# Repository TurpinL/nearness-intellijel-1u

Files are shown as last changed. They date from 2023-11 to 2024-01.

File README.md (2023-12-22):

# Nearness-Intellijel 1U

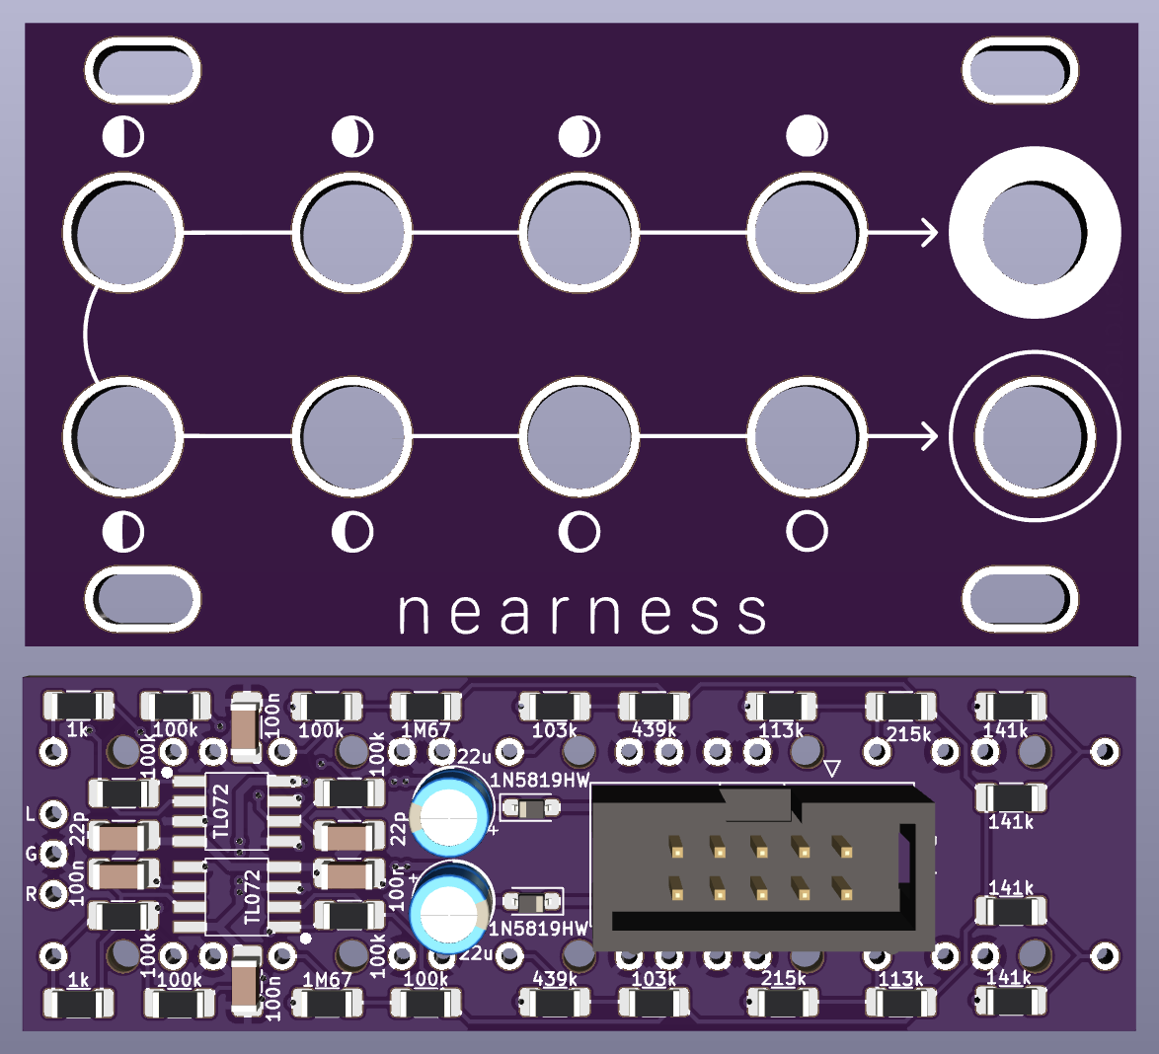
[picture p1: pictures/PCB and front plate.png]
Nearness Intellijel 1u


This is an adaption of [sonocircuit's nearness module 1u adaptation](https://github.com/sonocircuit/Nearness-1U) (Which itself is an 1u adaptation of [sarnesjo's nearness module](https://github.com/sarnesjo/nearness)) now in 1U Intellijel format. 

### Changes made:

- The back PCB is now 22.5mm high to fit Intellijel's spec
- Rearranged jacks, new faceplate
- 14hp
- Slightly adjusted resistor values based on availiability 

## Making your own

[Digikey BOM](https://www.digikey.com.au/en/mylists/list/PDI5ANLO88) **Note**: 3 pin header, 2x5 pin IDC Box header and jacks not included.

**WARNING**: I haven't yet assembled one of these to test it, there may be errors in and or all components of this. Build at your own risk!

**WARNING**: Watch out for the 3 pin header. It has to be soldered before the jacks, otherwise it's pads are inaccessible. You'll also want to trim its leads so they don't stick too far out the back of the PCB. It's best if the resulting solder mound is flat or recessed, otherwise it risks shorting out in the jack and/or the jack not sitting flat.

## Licence

Thanks to sarnesjo and sonocircuit for sharing! Same licence applies.

[CC BY-SA 4.0](http://creativecommons.org/licenses/by-sa/4.0/)

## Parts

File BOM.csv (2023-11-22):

# | Reference | Qty | Value | Footprint | Source
1 | C1, C2 | 2 | 22p | Capacitor_SMD:C_1206_3216Metric_Pad1.33x1.80mm_HandSolder | https://www.digikey.com.au/en/products/detail/w%C3%BCrth-elektronik/885012008039/5453738
2 | C3, C4 | 2 | 22u | Capacitor_THT:CP_Radial_D5.0mm_P2.00mm | https://www.digikey.com.au/en/products/detail/panasonic-electronic-components/ECE-A1EKA220/6921
3 | C5, C6, C7, C8 | 4 | 100n | Capacitor_SMD:C_1206_3216Metric_Pad1.33x1.80mm_HandSolder | https://www.digikey.com.au/en/products/detail/kemet/C1206C104K5RAC7210/3317012
4 | D1, D2 | 2 | Schottky | Diode_SMD:D_SOD-323_HandSoldering | https://www.digikey.com.au/en/products/detail/toshiba-semiconductor-and-storage/CUS10S40-H3F/5114300
5 | J1, J2, J3, J4, J5, J6, J7, J8, J9, J10 | 10 | PJ398SM | nearness: PJ398SM | https://www.thonk.co.uk/shop/thonkiconn/
6 | P1 | 1 | CONN_01X03 | nearness:Pin_1x3
7 | P7 | 1 | CONN_01X03 | Connector_IDC:IDC-Header_2x05_P2.54mm_Vertical
8 | R1, R14, R15, R17, R19, R20, R21, R22 | 8 | 100k | Resistor_SMD:R_1206_3216Metric_Pad1.30x1.75mm_HandSolder | https://www.digikey.com.au/en/products/detail/stackpole-electronics-inc/RMCF1206FT100K/1759689
9 | R2, R13 | 2 | 1M65 | Resistor_SMD:R_1206_3216Metric_Pad1.30x1.75mm_HandSolder | https://www.digikey.com.au/en/products/detail/vishay-dale/CRCW12061M65FKEA/1177009
10 | R3, R12 | 2 | 102k | Resistor_SMD:R_1206_3216Metric_Pad1.30x1.75mm_HandSolder | https://www.digikey.com.au/en/products/detail/stackpole-electronics-inc/RMCF1206FT102K/1759691
11 | R4, R11 | 2 | 442k | Resistor_SMD:R_1206_3216Metric_Pad1.30x1.75mm_HandSolder | https://www.digikey.com.au/en/products/detail/yageo/RC1206FR-07442KL/728921
12 | R5, R10 | 2 | 113k | Resistor_SMD:R_1206_3216Metric_Pad1.30x1.75mm_HandSolder | https://www.digikey.com.au/en/products/detail/vishay-dale/CRCW1206113KFKEA/1176877
13 | R6, R9 | 2 | 215k | Resistor_SMD:R_1206_3216Metric_Pad1.30x1.75mm_HandSolder | https://www.digikey.com.au/en/products/detail/yageo/RC1206FR-07215KL/728686
14 | R7, R8, R25, R26 | 4 | 140k | Resistor_SMD:R_1206_3216Metric_Pad1.30x1.75mm_HandSolder | https://www.digikey.com.au/en/products/detail/yageo/RC1206FR-07140KL/728550
15 | R23, R24 | 2 | 1k | Resistor_SMD:R_1206_3216Metric_Pad1.30x1.75mm_HandSolder | https://www.digikey.com.au/en/products/detail/stackpole-electronics-inc/RMCF1206FT1K00/1759616
16 | U1, U2 | 2 | TL072 | nearness:SOIC-8 | https://www.digikey.com.au/en/products/detail/texas-instruments/TL072HIDR/15205173

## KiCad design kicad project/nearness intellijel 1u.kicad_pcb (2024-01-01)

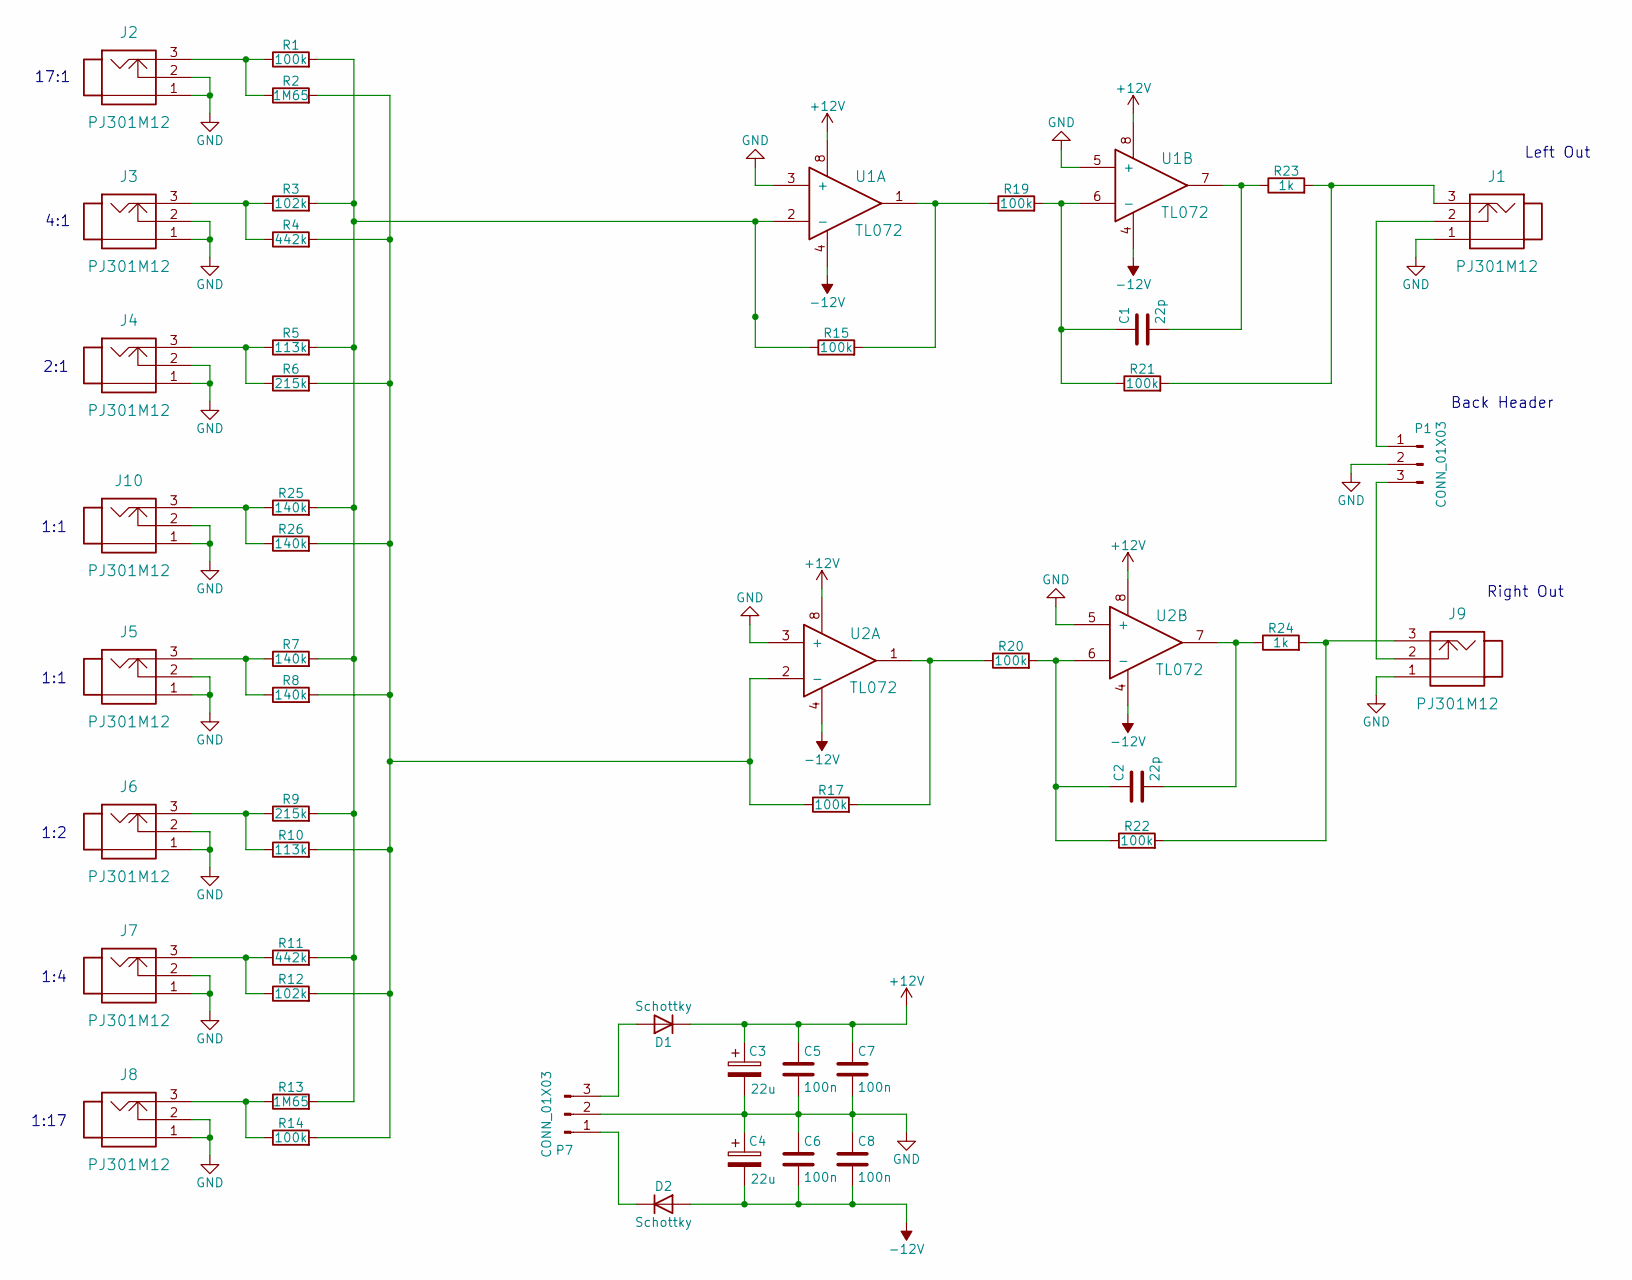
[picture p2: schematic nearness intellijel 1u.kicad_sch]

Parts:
C1, C2: 22p; C_1206_3216Metric_Pad1.33x1.80mm_HandSolder
C3, C4: 22u; CP_Radial_D5.0mm_P2.00mm
C5, C6, C7, C8: 100n; C_1206_3216Metric_Pad1.33x1.80mm_HandSolder
D1, D2: Schottky; D_SOD-323_HandSoldering
J1, J2, J3, J4, J5, J6, J7, J8, J9, J10: PJ301M12
P1: CONN_01X03; Pin_1x3
P7: CONN_01X03; IDC-Header_2x05_P2.54mm_Vertical
R1, R14, R15, R17, R19, R20, R21, R22: 100k; R_1206_3216Metric_Pad1.30x1.75mm_HandSolder
R2, R13: 1M65; R_1206_3216Metric_Pad1.30x1.75mm_HandSolder
R3, R12: 102k; R_1206_3216Metric_Pad1.30x1.75mm_HandSolder
R4, R11: 442k; R_1206_3216Metric_Pad1.30x1.75mm_HandSolder
R5, R10: 113k; R_1206_3216Metric_Pad1.30x1.75mm_HandSolder
R6, R9: 215k; R_1206_3216Metric_Pad1.30x1.75mm_HandSolder
R7, R8, R25, R26: 140k; R_1206_3216Metric_Pad1.30x1.75mm_HandSolder
R23, R24: 1k; R_1206_3216Metric_Pad1.30x1.75mm_HandSolder
U1, U2: TL072; SOIC-8

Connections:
+12V: C3.1, C5.1, C7.1, D1.1 (K), U1.8, U2.8
-12V: C4.2, C6.2, C8.2, D2.2 (A), U1.4, U2.4
GND: C3.2, C4.1, C5.2, C6.1, C7.2, C8.1, J1.1, J2.1, J2.2, J3.1, J3.2, J4.1, J4.2, J5.1, J5.2, J6.1, J6.2, J7.1, J7.2, J8.1, J8.2, J9.1, J10.1, J10.2, P1.2, P7.2, U1.3 (+), U1.5 (+), U2.3 (+), U2.5 (+)
unnamed: C1.2, R23.1, U1.7
unnamed: C2.2, R24.1, U2.7
unnamed: D1.2 (A), P7.3
unnamed: D2.1 (K), P7.1
unnamed: J1.3, R21.2, R23.2
unnamed: J2.3, R1.1, R2.1
unnamed: J3.3, R3.1, R4.1
unnamed: J4.3, R5.1, R6.1
unnamed: J5.3, R7.1, R8.1
unnamed: J6.3, R9.1, R10.1
unnamed: J7.3, R11.1, R12.1
unnamed: J8.3, R13.1, R14.1
unnamed: J9.3, R22.2, R24.2
unnamed: J10.3, R25.1, R26.1
unnamed: J1.2, P1.1
unnamed: J9.2, P1.3
unnamed: R15.2, R19.1, U1.1
unnamed: R17.2, R20.1, U2.1
unnamed: R1.2, R3.2, R5.2, R7.2, R9.2, R11.2, R13.2, R15.1, R25.2, U1.2 (-)
unnamed: C1.1, R19.2, R21.1, U1.6 (-)
unnamed: R2.2, R4.2, R6.2, R8.2, R10.2, R12.2, R14.2, R17.1, R26.2, U2.2 (-)
unnamed: C2.1, R20.2, R22.1, U2.6 (-)

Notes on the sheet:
2:1
1:4
1:1
4:1
Right Out
Left Out
17:1
1:2
1:17
Back Header

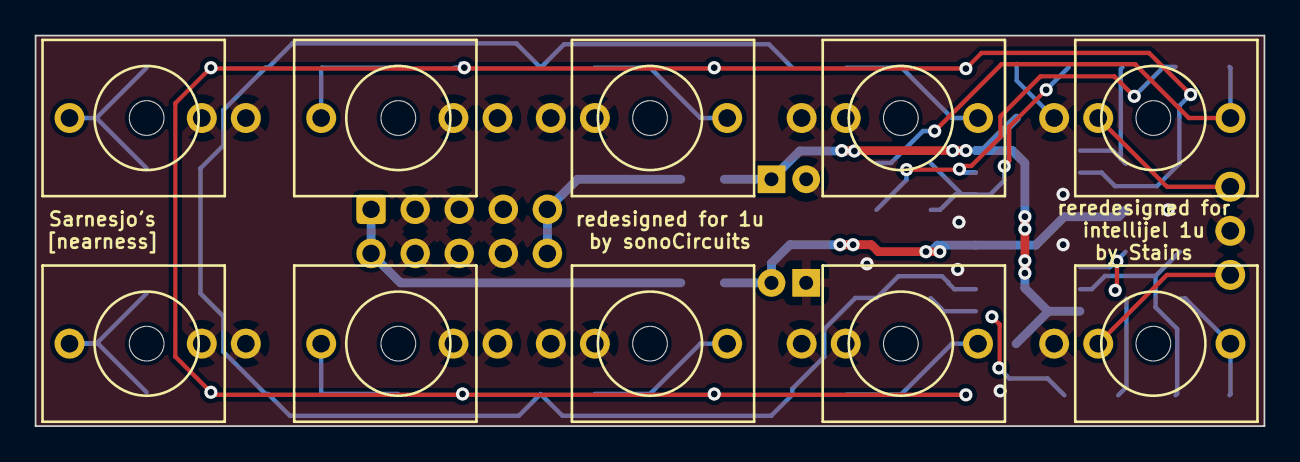
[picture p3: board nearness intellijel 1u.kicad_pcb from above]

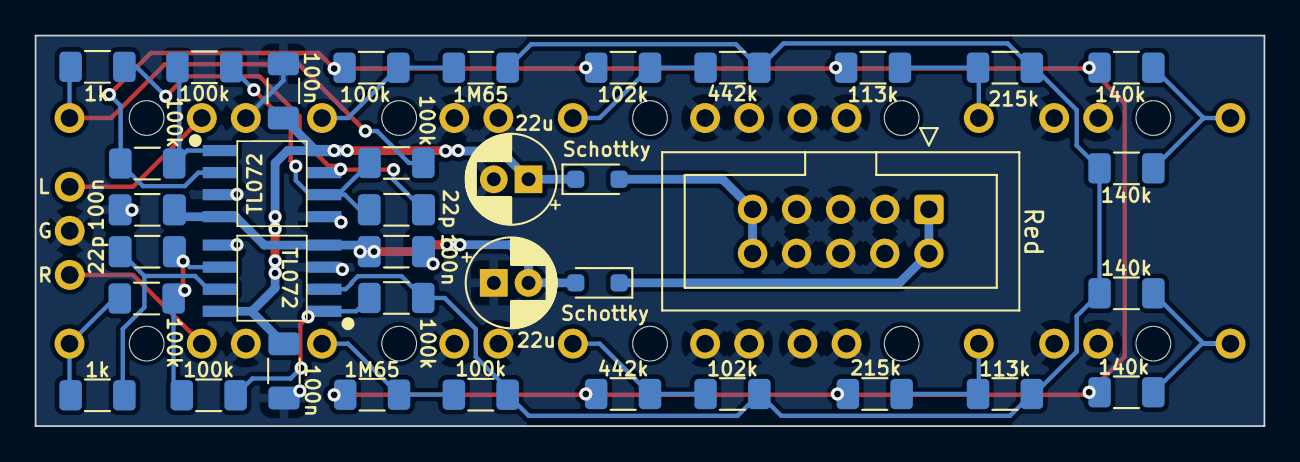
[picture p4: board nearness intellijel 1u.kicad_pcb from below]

Board: 2 copper layers, 70.8 x 22.5 mm, 48 parts (38 on the bottom side), 25 nets.

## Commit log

2023-11-22 Adjusted resistor values
    [nearness intellijel 1u.kicad_pcb, nearness intellijel 1u.kicad_sch]
2023-12-22 Fixed BOM link
2024-01-01 Fixed hole sizes and mislabeled component
    [nearness intellijel 1u front plate.kicad_pcb, nearness intellijel 1u.kicad_pcb]
